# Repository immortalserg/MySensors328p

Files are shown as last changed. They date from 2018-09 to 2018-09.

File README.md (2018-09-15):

# MySensors328p

Проект по разработке оборудования на микросхеме Atmega328p+Nrf24l01+

## MySensorsKey

4-х клавишный сенсорный выключатель
- беспроводной приемник-передатчик nrf24l01+
- управляющий процессор Atmega 328p с возможностью шифрования (ATSHA204-TSU) и дополнительной памятью (AT25xx).
- 4 сенсорные кнопки на микросхеме TTP224
- встроенный датчик температуры, давления и влажности BME280
- встроенный USB-UART преобразователь на микросхеме CP2102
- контроллер заряда аккумулятора (TP4056)
- аккумулятор 3,7 В формафактора до 70мм-50мм (рекомендуемый 305570 (55мм-70мм-3мм))

Корпус https://www.tinkercad.com/things/eCkWAxR6Mgm-mysensorskey#/

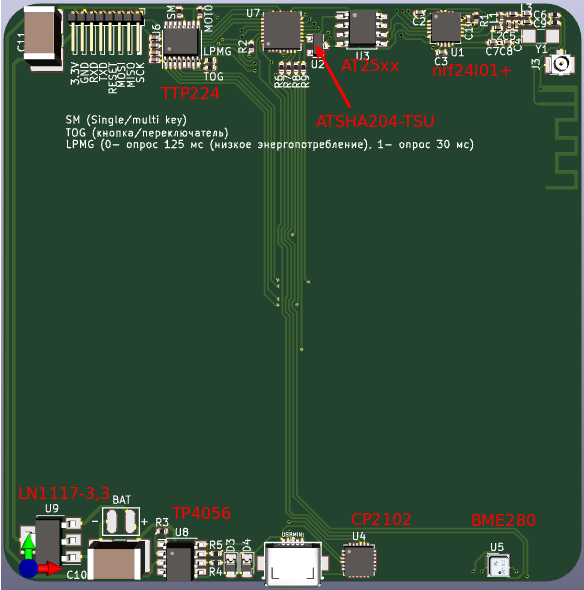
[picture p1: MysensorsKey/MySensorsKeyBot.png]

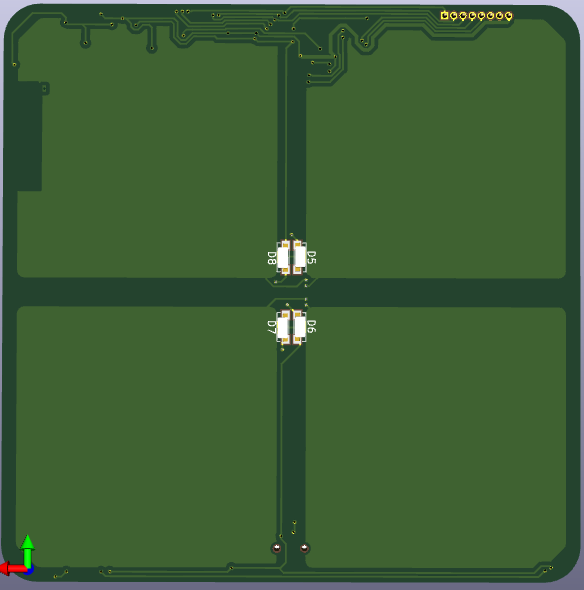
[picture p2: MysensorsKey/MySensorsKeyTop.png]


## MysensorsSensor

Универсальный датчик
- беспроводной приемник-передатчик nrf24l01+
- управляющий процессор Atmega 328p с возможностью шифрования (ATSHA204-TSU) и дополнительной памятью (AT25xx).
- встроенный датчик температуры, давления и влажности BME280
- встроенный USB-UART преобразователь на микросхеме CP2102
- контроллер заряда аккумулятора (TP4056)
- счетчик DS2423
- дополнительные выводы Atmega 328p
- аккумулятор 3,7 В формафактора 402020(20мм-20мм-4мм), 502020(20мм-20мм-5мм), 602020(20мм-20мм-5мм)

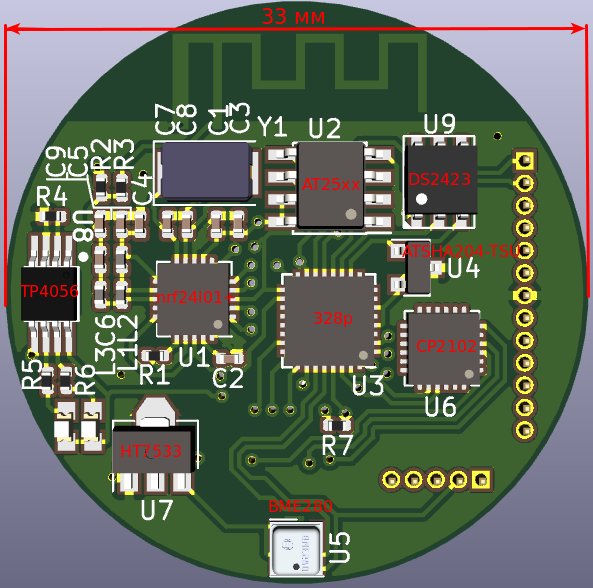
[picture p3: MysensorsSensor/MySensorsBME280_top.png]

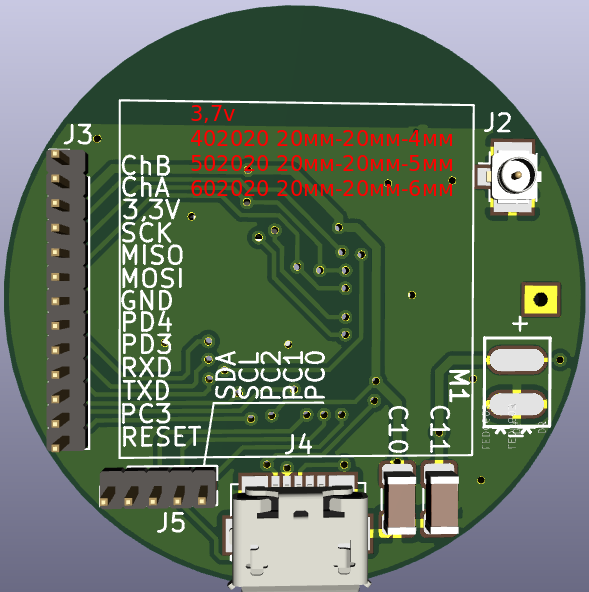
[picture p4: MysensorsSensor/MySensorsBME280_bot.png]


## MySensorsShield

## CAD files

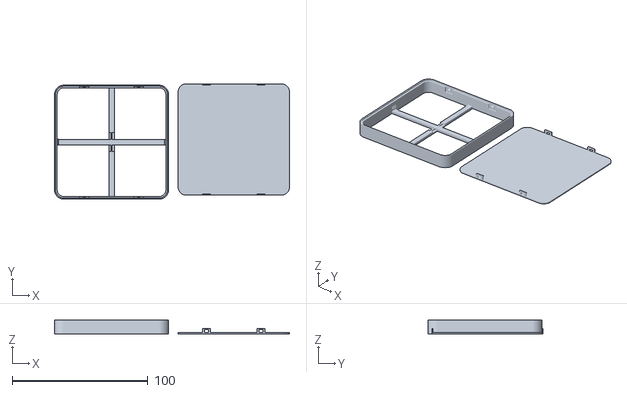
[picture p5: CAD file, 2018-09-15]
MysensorsKey/MySensorsKey.stl
173.0 x 85.0 x 10.0

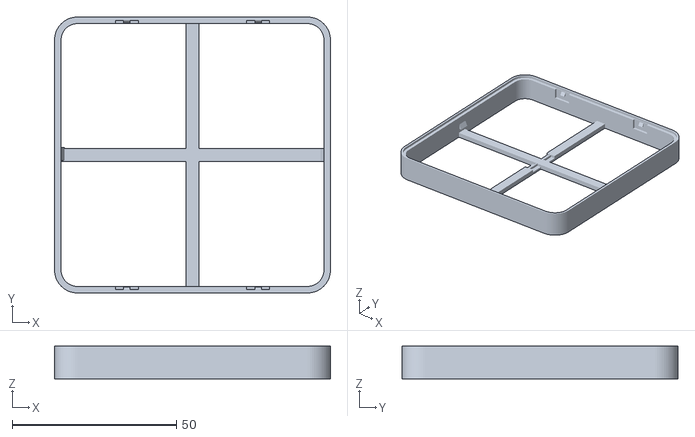
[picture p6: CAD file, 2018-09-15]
MysensorsKey/MySensorsKey1.stl
84.0 x 84.0 x 10.0

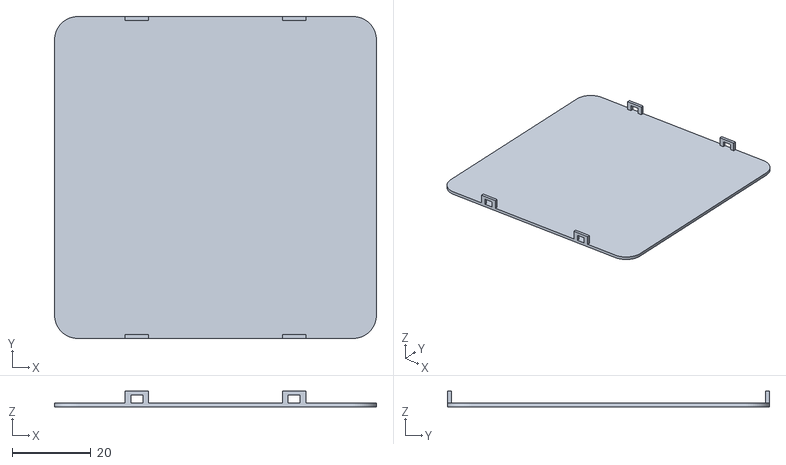
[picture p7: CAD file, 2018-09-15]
MysensorsKey/MySensorsKey2.stl
82.0 x 82.0 x 4.00

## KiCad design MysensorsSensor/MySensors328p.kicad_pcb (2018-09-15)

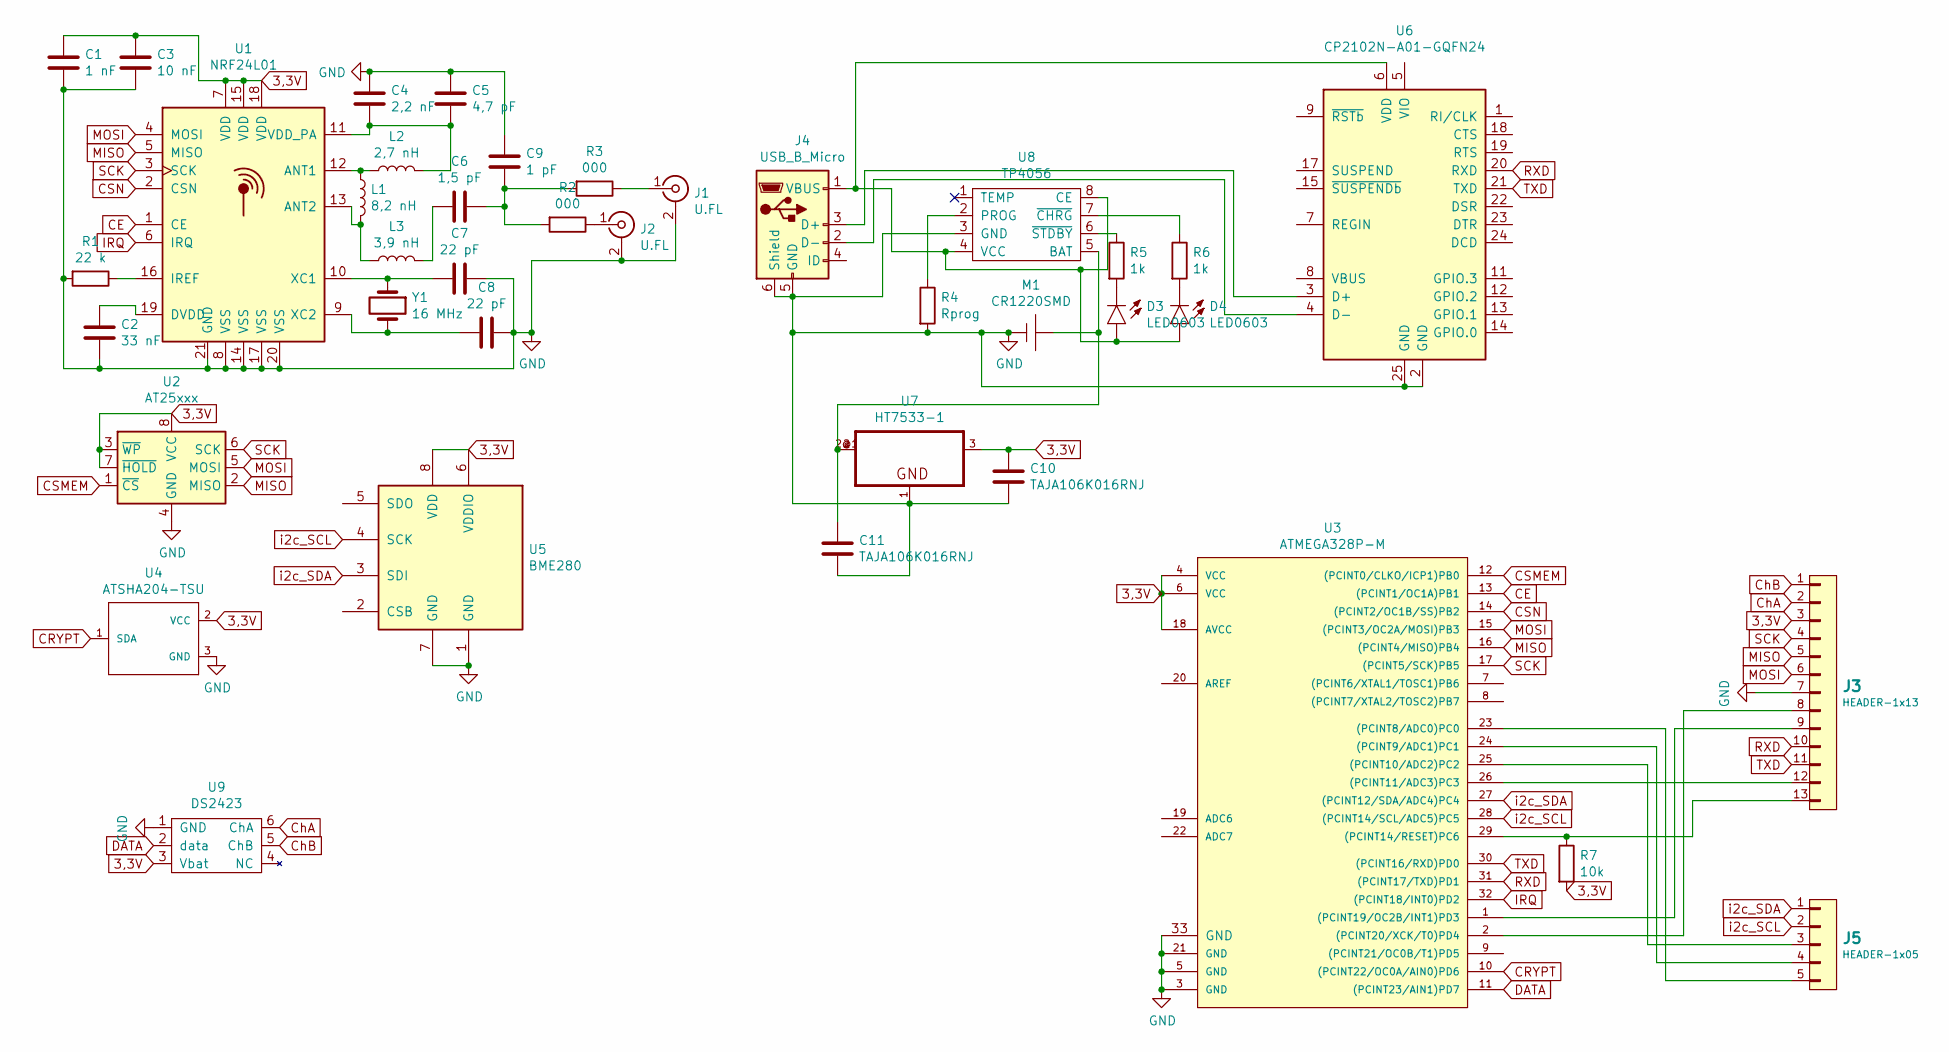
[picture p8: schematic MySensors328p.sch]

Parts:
C1: 1 nF; C_0402_1005Metric
C2: 33 nF; C_0402_1005Metric
C3: 10 nF; C_0402_1005Metric
C4: 2,2 nF; C_0402_1005Metric
C5: 4,7 pF; C_0402_1005Metric
C6: 1,5 pF; C_0402_1005Metric
C7, C8: 22 pF; C_0402_1005Metric
C9: 1 pF; C_0402_1005Metric
C10, C11: TAJA106K016RNJ; C_1206_3216Metric
D3, D4: LED0603; LED-0603
J1: U.FL; Texas_SWRA117D_2.4GHz_Right
J2: U.FL; U.FL_Hirose_U.FL-R-SMT-1_Vertical
J3: HEADER-1x13; PinHeader_1x13_P1.27mm_Vertical
J4: USB_B_Micro; USB_Micro-B_Molex_47346-0001
J5: HEADER-1x05; PinHeader_1x05_P1.27mm_Vertical
L1: 8,2 nH; L_0402_1005Metric
L2: 2,7 nH; L_0402_1005Metric
L3: 3,9 nH; L_0402_1005Metric
M1: CR1220SMD; WP-50mil-1x02
R1: 22 k; R_0402_1005Metric
R2, R3: 000; R_0402_1005Metric
R4: Rprog; R_0402_1005Metric
R5, R6: 1k; R_0402_1005Metric
R7: 10k; R_0402_1005Metric
U1: NRF24L01; QFN-20-1EP_4x4mm_P0.5mm_EP2.5x2.5mm
U2: AT25xxx; SOIC-8_3.9x4.9mm_P1.27mm
U3: ATMEGA328P-M; QFN-32-1EP_5x5mm_P0.5mm_EP3.45x3.45mm
U4: ATSHA204-TSU; SOT-23
U5: BME280; bme280
U6: CP2102N-A01-GQFN24; QFN-24-1EP_4x4mm_P0.5mm_EP2.6x2.6mm
U7: HT7533-1; SOT-89-3
U8: TP4056; PPSOP8
U9: DS2423; tsoc-6
Y1: 16 MHz; Crystal_SMD_5032-2Pin_5.0x3.2mm

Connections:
3,3V: C1.1, C3.1, C10.1, J3.3, R7.2, U1.7 (VDD), U1.15 (VDD), U1.18 (VDD), U2.3 (~WP), U2.7 (~HOLD), U2.8 (VCC), U3.4 (VCC), U3.6 (VCC), U3.18 (AVCC), U4.2 (VCC), U5.6 (VDDIO), U5.8 (VDD), U7.3 (VO), U9.3 (Vbat)
CE: U1.1 (CE), U3.13 ((PCINT1/OC1A)PB1)
CRYPT: U3.10 ((PCINT22/OC0A/AIN0)PD6), U4.1 (SDA)
CSMEM: U2.1 (~CS), U3.12 ((PCINT0/CLKO/ICP1)PB0)
CSN: U1.2 (CSN), U3.14 ((PCINT2/OC1B/SS)PB2)
ChA: J3.2, U9.6 (ChA)
ChB: J3.1, U9.5 (ChB)
DATA: U3.11 ((PCINT23/AIN1)PD7), U9.2 (data)
GND: C1.2, C2.2, C3.2, C4.1, C5.1, C7.1, C8.1, C9.1, C10.2, C11.2, J1.2 (Ext), J2.2 (Ext), J3.7, J4.5 (GND), J4.6 (Shield), M1.1 (-), R1.2, R4.2, U1.8 (VSS), U1.14 (VSS), U1.17 (VSS), U1.20 (VSS), U1.21 (GND), U2.4 (GND), U3.3 (GND), U3.5 (GND), U3.21 (GND), U3.33 (GND), U4.3 (GND), U5.1 (GND), U5.7 (GND), U6.2 (GND), U6.25 (GND), U7.1 (GND), U8.3 (GND), U9.1 (GND)
IRQ: U1.6 (IRQ), U3.32 ((PCINT18/INT0)PD2)
MISO: J3.5, U1.5 (MISO), U2.2 (MISO), U3.16 ((PCINT4/MISO)PB4)
MOSI: J3.6, U1.4 (MOSI), U2.5 (MOSI), U3.15 ((PCINT3/OC2A/MOSI)PB3)
unnamed: C2.1, U1.19 (DVDD)
unnamed: C4.2, C5.2, L2.2, U1.11 (VDD_PA)
unnamed: C6.1, C9.2, R2.2, R3.2
unnamed: C6.2, L3.2
unnamed: C7.2, U1.10 (XC1), Y1.1
unnamed: C8.2, U1.9 (XC2), Y1.2
unnamed: C11.1, M1.2 (+), U7.2 (VI), U7.2@1 (VI), U8.5 (BAT)
unnamed: D3.A, D4.A, J4.1 (VBUS), U6.6 (VDD), U8.4 (VCC), U8.8 (CE)
unnamed: D3.C, R5.2
unnamed: D4.C, R6.2
unnamed: J1.1 (In), R3.1
unnamed: J2.1 (In), R2.1
unnamed: J3.8, U3.2 ((PCINT20/XCK/T0)PD4)
unnamed: J3.9, U3.1 ((PCINT19/OC2B/INT1)PD3)
unnamed: J3.12, U3.26 ((PCINT11/ADC3)PC3)
unnamed: J3.13, R7.1, U3.29 ((PCINT14/RESET)PC6)
unnamed: J4.2 (D-), U6.4 (D-)
unnamed: J4.3 (D+), U6.3 (D+)
unnamed: J5.3, U3.25 ((PCINT10/ADC2)PC2)
unnamed: J5.4, U3.24 ((PCINT9/ADC1)PC1)
unnamed: J5.5, U3.23 ((PCINT8/ADC0)PC0)
unnamed: L1.1, L2.1, U1.12 (ANT1)
unnamed: L1.2, L3.1, U1.13 (ANT2)
unnamed: R1.1, U1.16 (IREF)
unnamed: R4.1, U8.2 (PROG)
unnamed: R5.1, U8.6 (~STDBY)
unnamed: R6.1, U8.7 (~CHRG)
RXD: J3.10, U3.31 ((PCINT17/TXD)PD1), U6.20 (RXD)
SCK: J3.4, U1.3 (SCK), U2.6 (SCK), U3.17 ((PCINT5/SCK)PB5)
TXD: J3.11, U3.30 ((PCINT16/RXD)PD0), U6.21 (TXD)
i2c_SCL: J5.2, U3.28 ((PCINT14/SCL/ADC5)PC5), U5.4 (SCK)
i2c_SDA: J5.1, U3.27 ((PCINT12/SDA/ADC4)PC4), U5.3 (SDI)

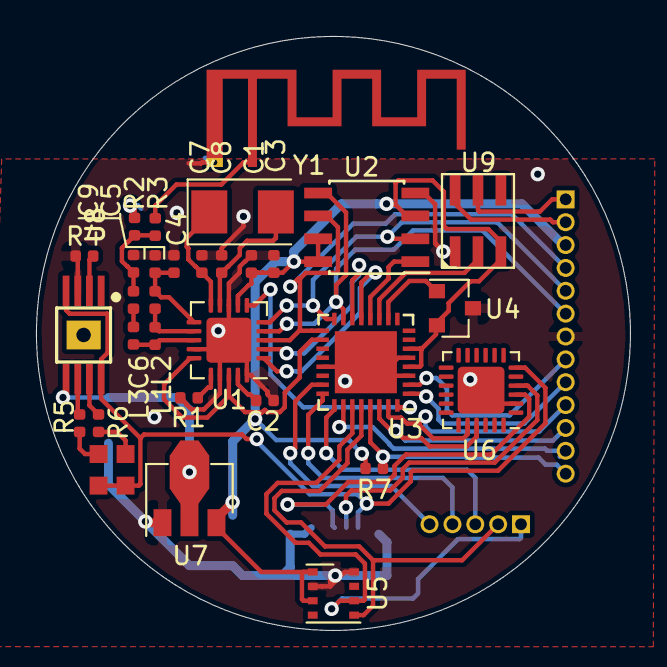
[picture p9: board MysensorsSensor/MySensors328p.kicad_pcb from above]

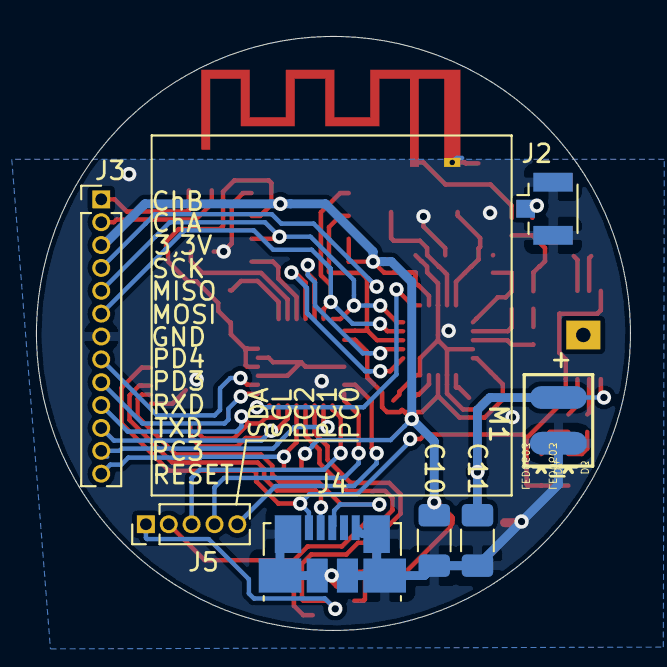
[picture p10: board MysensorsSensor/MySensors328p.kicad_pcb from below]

Board: 2 copper layers, 33.0 x 33.0 mm, 39 parts (7 on the bottom side), 44 nets.

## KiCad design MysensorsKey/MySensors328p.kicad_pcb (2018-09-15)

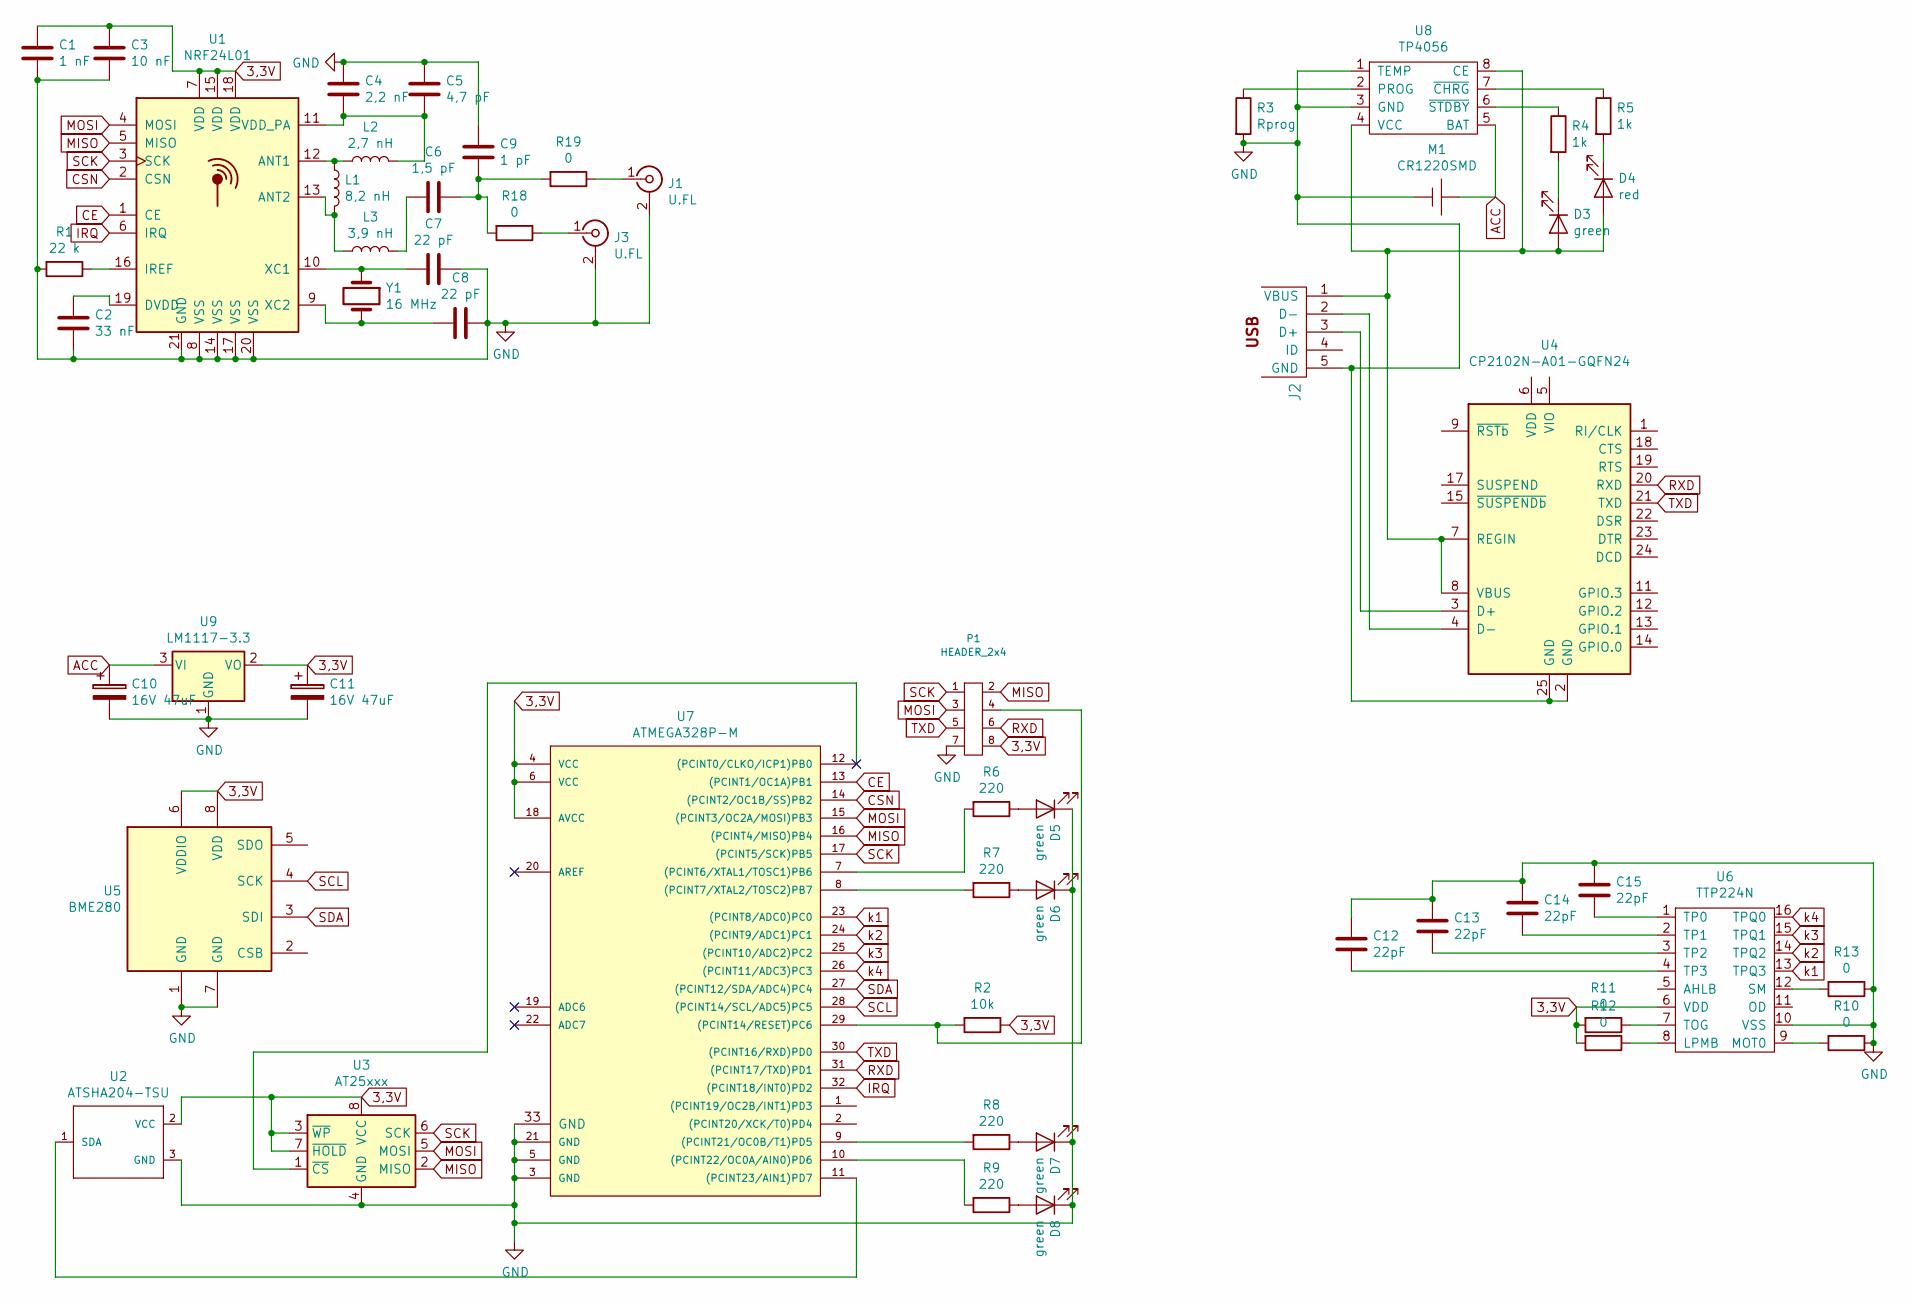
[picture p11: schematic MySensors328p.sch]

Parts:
C1: 1 nF; C_0402_1005Metric
C2: 33 nF; C_0402_1005Metric
C3: 10 nF; C_0402_1005Metric
C4: 2,2 nF; C_0402_1005Metric
C5: 4,7 pF; C_0402_1005Metric
C6: 1,5 pF; C_0402_1005Metric
C7, C8: 22 pF; C_0402_1005Metric
C9: 1 pF; C_0402_1005Metric
C10, C11: 16V 47uF; C_2816_7142Metric_Pad3.20x4.45mm_HandSolder
C12, C13, C14, C15: 22pF; C_0402_1005Metric
D3: green; D_0805_2012Metric_Pad1.15x1.40mm_HandSolder
D4: red; D_0805_2012Metric_Pad1.15x1.40mm_HandSolder
D5, D6, D7, D8: green; smd_led_4008
J1: U.FL; Texas_SWRA117D_2.4GHz_Right
J2: USBMINI; conn_usb_B_micro_smd-3
J3: U.FL; U.FL_Hirose_U.FL-R-SMT-1_Vertical
L1: 8,2 nH; L_0402_1005Metric
L2: 2,7 nH; L_0402_1005Metric
L3: 3,9 nH; L_0402_1005Metric
M1: CR1220SMD; WP-50mil-1x02
P1: HEADER_2x4; PinHeader_1x08_P1.27mm_Horizontal
R1: 22 k; R_0402_1005Metric
R2: 10k; R_0402_1005Metric
R3: Rprog; R_0402_1005Metric
R4, R5: 1k; R_0402_1005Metric
R6, R7, R8, R9: 220; R_0402_1005Metric
R10, R11, R12, R13, R18, R19: 0; R_0402_1005Metric
U1: NRF24L01; QFN-20-1EP_4x4mm_P0.5mm_EP2.5x2.5mm
U2: ATSHA204-TSU; SOT-23
U3: AT25xxx; SOIC-8_3.9x4.9mm_P1.27mm
U4: CP2102N-A01-GQFN24; QFN-24-1EP_4x4mm_P0.5mm_EP2.6x2.6mm
U5: BME280; bme280
U6: TTP224N; SSOP-16_3.9x4.9mm_P0.635mm
U7: ATMEGA328P-M; QFN-32-1EP_5x5mm_P0.5mm_EP3.45x3.45mm
U8: TP4056; SSOP-8_3.95x5.21x3.27mm_P1.27mm
U9: LM1117-3.3; SOT-223-3_TabPin2
Y1: 16 MHz; Crystal_SMD_MicroCrystal_CC7V-T1A-2Pin_3.2x1.5mm_HandSolder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

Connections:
3,3V: C1.1, C3.1, C11.1, P1.8, R2.1, R11.2, R12.2, U1.7 (VDD), U1.15 (VDD), U1.18 (VDD), U2.2 (VCC), U3.3 (~WP), U3.7 (~HOLD), U3.8 (VCC), U5.6 (VDDIO), U5.8 (VDD), U6.6 (VDD), U7.4 (VCC), U7.6 (VCC), U7.18 (AVCC), U9.2 (VO)
ACC: C10.1, M1.2 (+), U8.5 (BAT), U9.3 (VI)
CE: U1.1 (CE), U7.13 ((PCINT1/OC1A)PB1)
CSN: U1.2 (CSN), U7.14 ((PCINT2/OC1B/SS)PB2)
GND: C1.2, C2.2, C3.2, C4.1, C5.1, C7.1, C8.1, C9.1, C10.2, C11.2, C12.1, C13.1, C14.1, C15.1, D5.1 (K), D6.1 (K), D7.1 (K), D8.1 (K), J1.2 (Ext), J2.5 (GND), J3.2 (Ext), M1.1 (-), P1.7, R1.2, R3.2, R10.1, R13.1, U1.8 (VSS), U1.14 (VSS), U1.17 (VSS), U1.20 (VSS), U1.21 (GND), U2.3 (GND), U3.4 (GND), U4.2 (GND), U4.25 (GND), U5.1 (GND), U5.7 (GND), U6.10 (VSS), U7.3 (GND), U7.5 (GND), U7.21 (GND), U7.33 (GND), U8.1 (TEMP), U8.3 (GND), U9.1 (GND)
IRQ: U1.6 (IRQ), U7.32 ((PCINT18/INT0)PD2)
MISO: P1.2 (P1), U1.5 (MISO), U3.2 (MISO), U7.16 ((PCINT4/MISO)PB4)
MOSI: P1.3 (P2), U1.4 (MOSI), U3.5 (MOSI), U7.15 ((PCINT3/OC2A/MOSI)PB3)
unnamed: C2.1, U1.19 (DVDD)
unnamed: C4.2, C5.2, L2.2, U1.11 (VDD_PA)
unnamed: C6.1, C9.2, R18.2, R19.2
unnamed: C6.2, L3.2
unnamed: C7.2, U1.10 (XC1), Y1.1
unnamed: C8.2, U1.9 (XC2), Y1.2
unnamed: C12.2, U6.4 (TP3)
unnamed: C13.2, U6.3 (TP2)
unnamed: C14.2, U6.2 (TP1)
unnamed: C15.2, U6.1 (TP0)
unnamed: D3.1 (K), R4.2
unnamed: D3.2 (A), D4.2 (A), J2.1 (VBUS), U4.7 (REGIN), U4.8 (VBUS), U8.4 (VCC), U8.8 (CE)
unnamed: D4.1 (K), R5.2
unnamed: D5.2 (A), R6.1
unnamed: D6.2 (A), R7.1
unnamed: D7.2 (A), R8.1
unnamed: D8.2 (A), R9.1
unnamed: J1.1 (In), R19.1
unnamed: J2.2 (D-), U4.4 (D-)
unnamed: J2.3 (D+), U4.3 (D+)
unnamed: J3.1 (In), R18.1
unnamed: L1.1, L2.1, U1.12 (ANT1)
unnamed: L1.2, L3.1, U1.13 (ANT2)
unnamed: P1.4 (P2), R2.2, U7.29 ((PCINT14/RESET)PC6)
unnamed: R1.1, U1.16 (IREF)
unnamed: R3.1, U8.2 (PROG)
unnamed: R4.1, U8.6 (~STDBY)
unnamed: R5.1, U8.7 (~CHRG)
unnamed: R6.2, U7.7 ((PCINT6/XTAL1/TOSC1)PB6)
unnamed: R7.2, U7.8 ((PCINT7/XTAL2/TOSC2)PB7)
unnamed: R8.2, U7.9 ((PCINT21/OC0B/T1)PD5)
unnamed: R9.2, U7.10 ((PCINT22/OC0A/AIN0)PD6)
unnamed: R10.2, U6.9 (MOT0)
unnamed: R11.1, U6.7 (TOG)
unnamed: R12.1, U6.8 (LPMB)
unnamed: R13.2, U6.12 (SM)
unnamed: U2.1 (SDA), U7.11 ((PCINT23/AIN1)PD7)
unnamed: U3.1 (~CS), U7.12 ((PCINT0/CLKO/ICP1)PB0)
RXD: P1.6, U4.20 (RXD), U7.31 ((PCINT17/TXD)PD1)
SCK: P1.1, U1.3 (SCK), U3.6 (SCK), U7.17 ((PCINT5/SCK)PB5)
SCL: U5.4 (SCK), U7.28 ((PCINT14/SCL/ADC5)PC5)
SDA: U5.3 (SDI), U7.27 ((PCINT12/SDA/ADC4)PC4)
TXD: P1.5, U4.21 (TXD), U7.30 ((PCINT16/RXD)PD0)
k1: U6.13 (TPQ3), U7.23 ((PCINT8/ADC0)PC0)
k2: U6.14 (TPQ2), U7.24 ((PCINT9/ADC1)PC1)
k3: U6.15 (TPQ1), U7.25 ((PCINT10/ADC2)PC2)
k4: U6.16 (TPQ0), U7.26 ((PCINT11/ADC3)PC3)

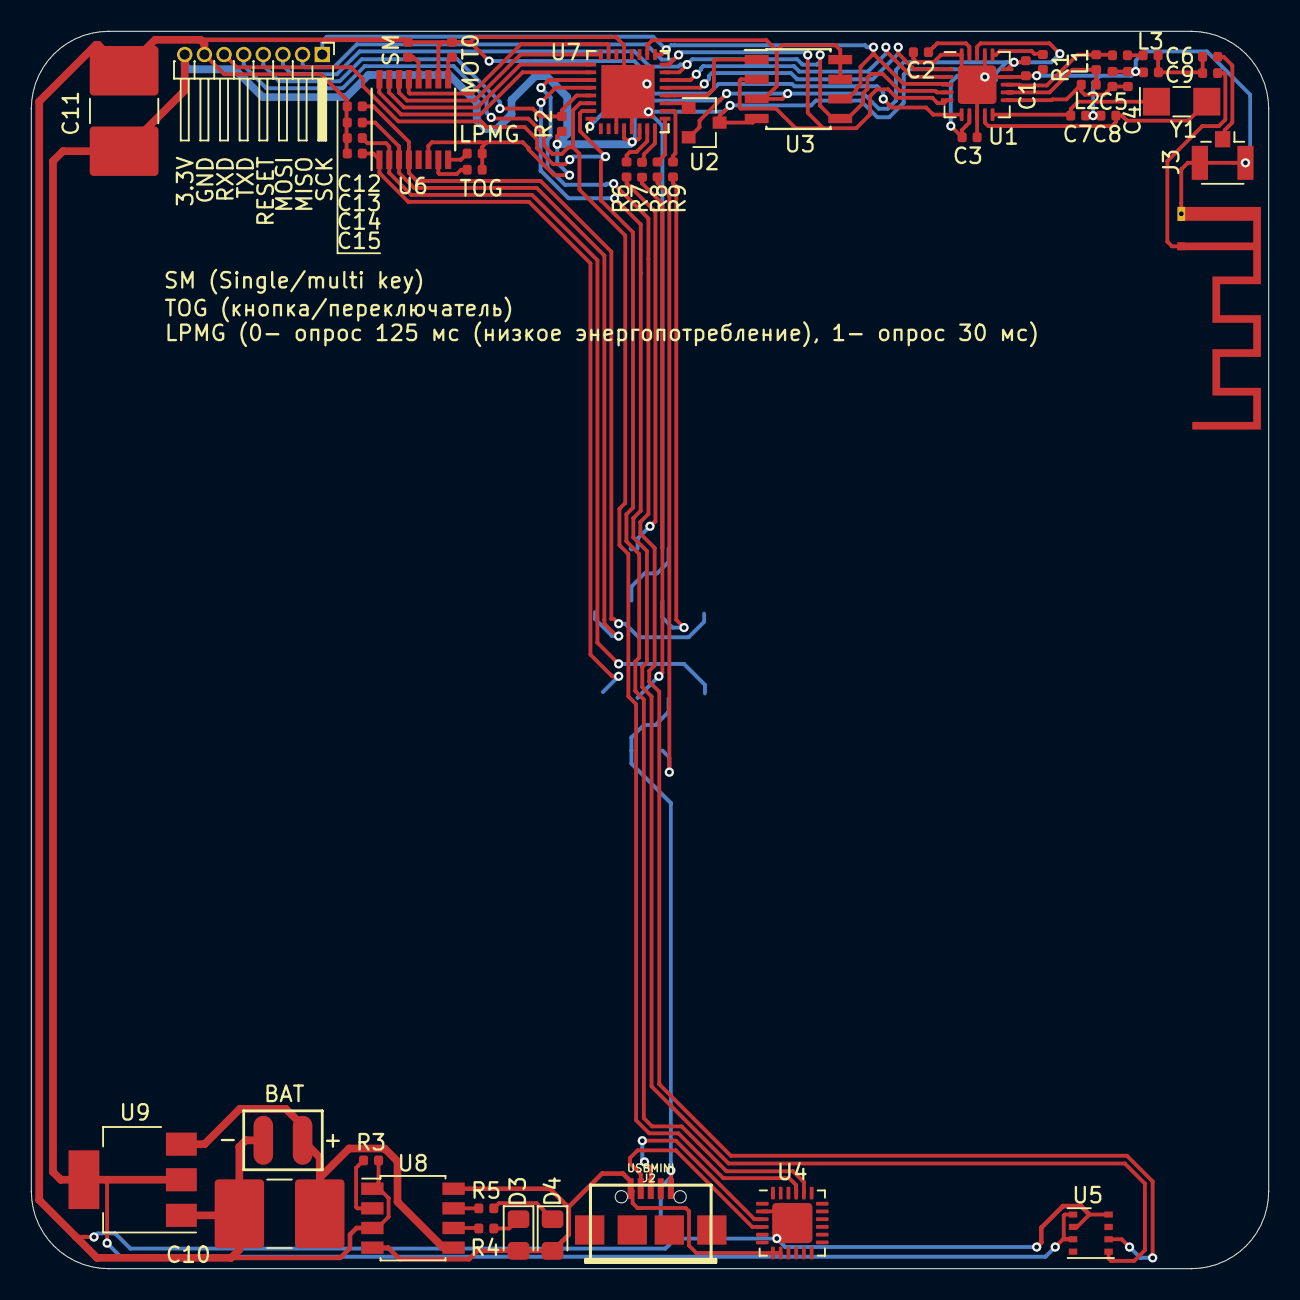
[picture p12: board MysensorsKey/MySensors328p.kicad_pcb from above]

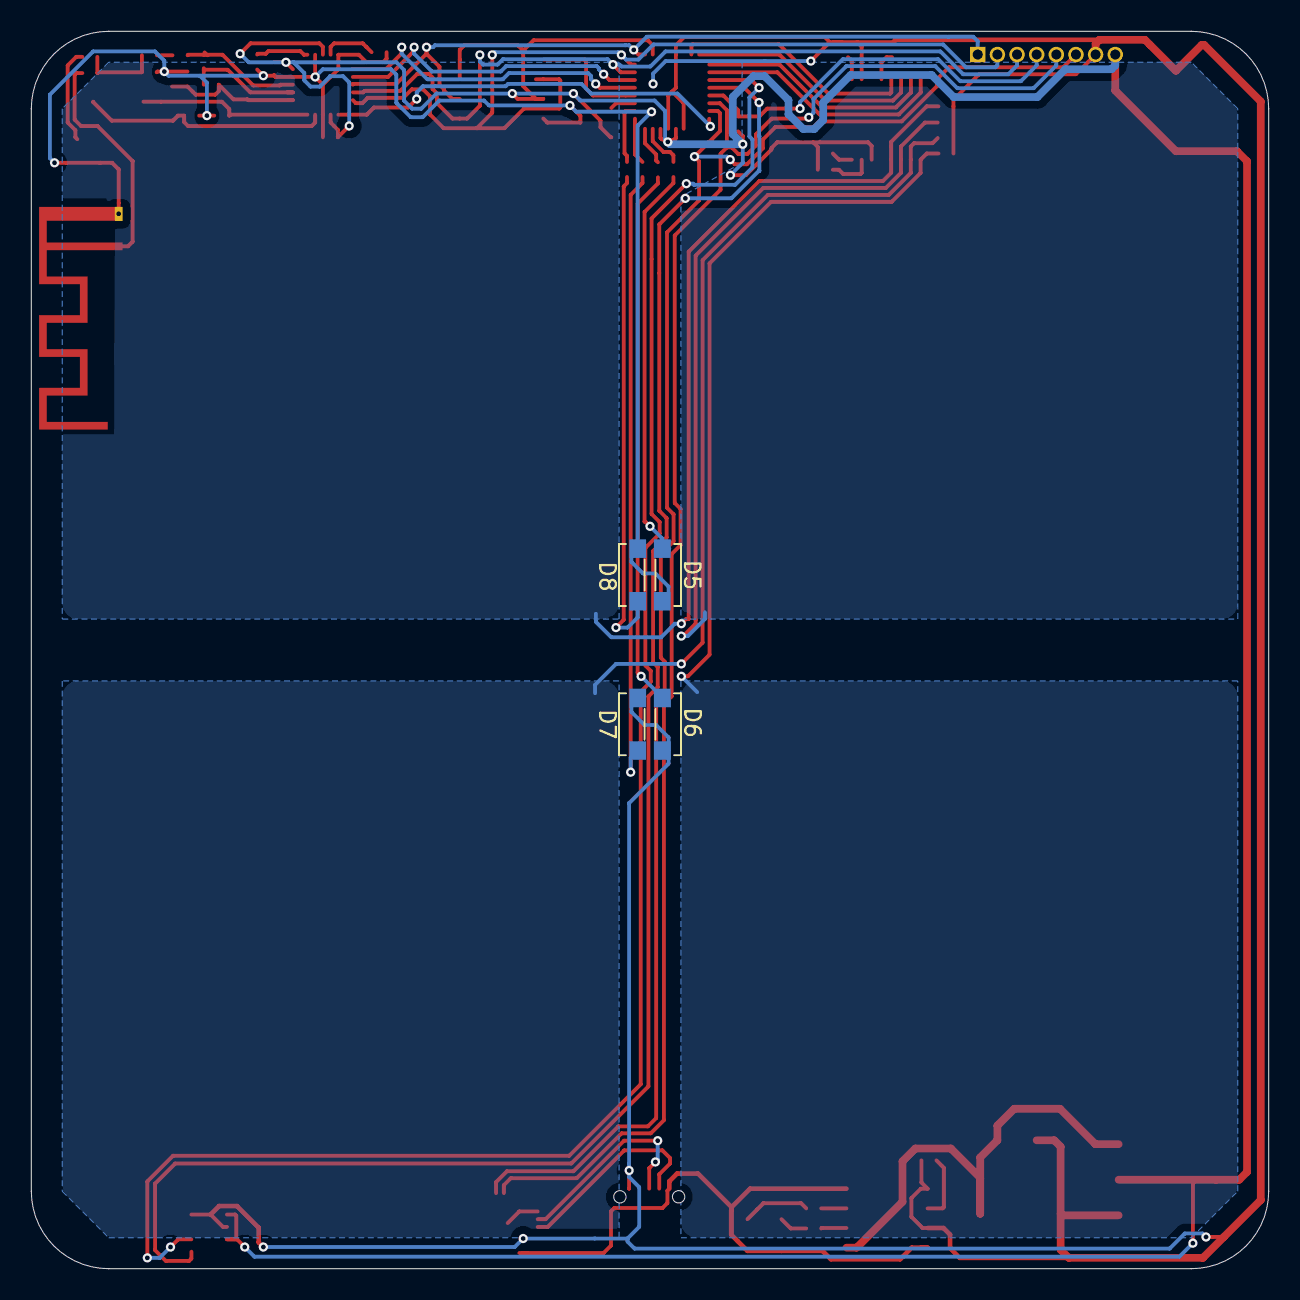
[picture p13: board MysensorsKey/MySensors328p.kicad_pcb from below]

Board: 2 copper layers, 80.0 x 80.0 mm, 54 parts (4 on the bottom side), 55 nets.
